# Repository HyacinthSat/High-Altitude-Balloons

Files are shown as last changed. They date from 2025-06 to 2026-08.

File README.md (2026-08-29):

# High-Altitude-Balloons  

~~高空气球，穷人的太空计划~~  
本仓库托管了风信子卫星项目下的一个高空气球项目  

该项目的主要目标为高空图像采集与回传，并围绕此目标开发了一系列的软件与硬件解决方案  
借助实现主要目的基本硬件，额外实现了业余无线电数字中继等功能  

主要作者：[BG7ZDQ](https://github.com/X-MQSI)  
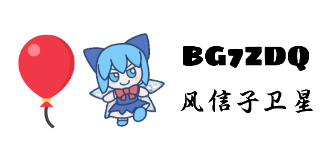
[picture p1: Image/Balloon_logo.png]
气球标识
  

飞行数据仪表板: [hab.satellites.ac.cn](https://hab.satellites.ac.cn/)  

## 项目功能  

- **实时遥测与追踪**：通过地面站实时接收、解析并展示气球的 GPS 位置、高度、速度、航向等关键遥测数据  
- **图像拍摄与回传**：支持将机载摄像头拍摄的图像通过 SSDV 协议进行编码和下传，并在地面站实时解码显示  
- **业余无线电通信**：集成数字中继功能，允许业余无线电爱好者通过气球作为数字中继进行远距离的通信实验  
- **Web 数据仪表板**：提供集成仪表板，整合了 SondeHub 实时追踪、飞行轨迹预测和遥测数据可视化图表  

## 系统展示  

- **气球载荷**  
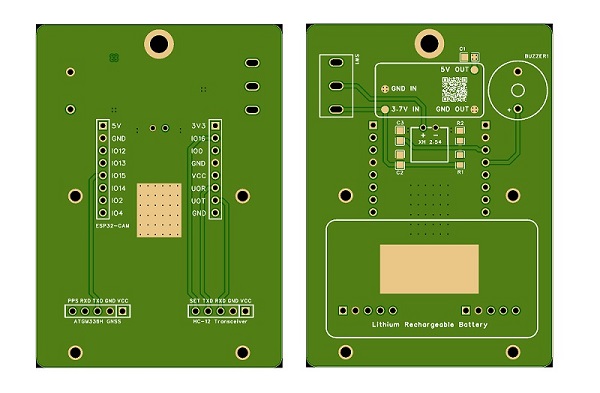
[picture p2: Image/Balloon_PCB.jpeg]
Balloon_PCB_仿真
  

- **可配置数传单元**  
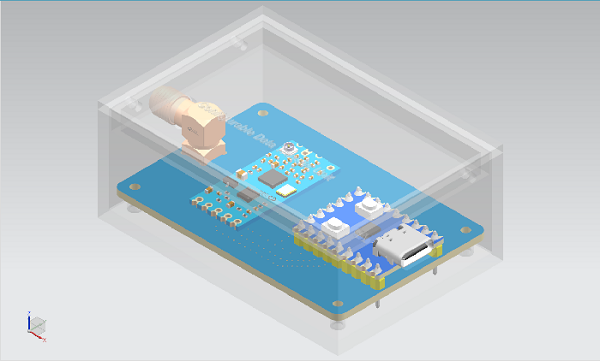
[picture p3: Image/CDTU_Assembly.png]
CDTU_装配


- **地面站程序**  
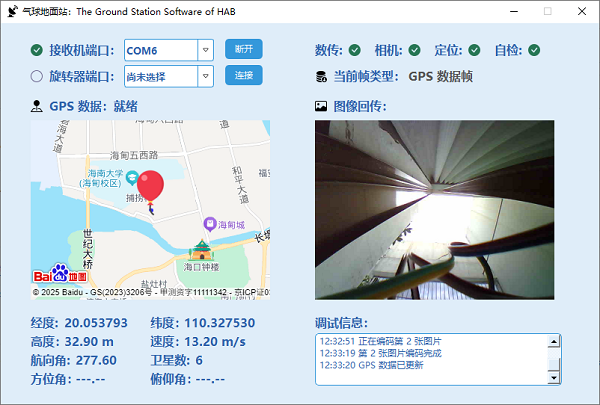
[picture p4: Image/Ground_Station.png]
Ground_Station


## 系统架构  
整个项目由三个主要部分组成：  

1. **[Balloon | 气球载荷](./Balloon)**  
气球飞行的核心控制器，负责所有机载任务。

- `/Balloon.h`: 定义了外设（如摄像头、传感器）的硬件引脚  
- `/Balloon.ino`: 主控程序。负责初始化板载硬件、采集传感器数据、构建遥测帧、捕获图像并使用 SSDV 协议编码，同时处理数字中继功能  
- `/ssdv.c` & `/ssdv.h`: SSDV 图像编码库。实现了将 JPEG 图像转换为一系列可无线传输的数据包的逻辑，来自 [fsphil ssdv](https://github.com/fsphil/ssdv/)  
- `/rs8.c` & `/rs8.h`: Reed-Solomon 前向错误校验库，为 SSDV 数据包提供容错能力，来自 [fsphil ssdv](https://github.com/fsphil/ssdv/)  
- `/Balloon_PCB_Ver_1.0.3.zip`: 气球端的电路设计，PCB制版文件、预览图片及其3D模型。使用立创 EDA 绘制  

2. **[CDTU | 可配置数传单元](./CDTU)**  
基于 RP2040-Zero 的智能数传模块控制器。  

- `/main.py`: 运行在 RP2040-Zero 上的核心程序。它将普通的 HC-12 数传模块升级为一个智能可配置的数传单元，实现了：  
  - 简易功能配置：免去了对硬件进行直接操作，智能识别解析配置指令，动态调整模块的参数  
  - 自适应波特率：存储了模块的配置参数，解决了串口通信的波特率管理问题    
  - 自动模式切换：通过硬件引脚控制模块在数据模式和命令模式间无缝切换  
  - 透明数据桥接：在默认模式下作为完全透明的数据传输桥  

- `CDTU_PCB_Ver_1.0.1.zip`: CDTU 的电路设计，PCB制版文件、预览图片及其3D模型。使用立创 EDA 绘制  

3. **[Ground Station | 地面站](./Ground%20Station)**  
功能强大的图形化地面站软件，是数据接收、状态监控和任务执行的控制中心。  

- `/GUI.py`: 基于 PyQt6 的地面站图形化主程序。 它负责：  
  - 连接、管理和控制测控用收发信机 CDTU  
  - 连接、管理和控制追踪气球的旋转器  
  - 气球的控制与状态监测  
  - 解析遥测、SSDV 图像数据和中继通信数据  
  - 上传数据至 SondeHub 进行多站点协作  
  - 基于遥测数据绘制实时轨迹  
  - 提供数字中继的客户端  

- `/sondehub.*`: 命令行工具，用于将遥测数据上传至 SondeHub  

- `/ssdv.exe`: 用于解码气球回传的 SSDV 协议图像的预编译程序，编译自 [fsphil ssdv](https://github.com/fsphil/ssdv/)。  

- `/web/`: 地面站 GUI 内嵌的地图和仪表板网页文件  
        * `map.html` & `map.js`: 内嵌于GUI的百度地图页面，用于显示气球和地面站的实时位置与轨迹  
        * `coordtransform.js`: 用于在不同地理坐标系之间转换的库，确保地图定位准确  
        * `index.html`: 项目主数据面板，简单整合了 SondeHub 实时追踪、飞行预测和 Grafana 遥测仪表盘  

## 使用说明  

1. **Ground Station | 地面站**  
- 运行环境:  
  - Python 3.11.0 及 相关依赖库：  
  (`pip install PyQt6 PyQt6-WebEngine pyserial numpy`)  

## 注意事项  

地面站程序使用了百度地图api，您可以直接使用 [https://hab.satellites.ac.cn/map](https://hab.satellites.ac.cn/map) ，或者将 `Ground Station/web` 目录下的内容托管到自己的服务器。  

## 开源许可  

本仓库在 MIT 许可证下发布。  
这意味着：  

- 任何人均可自由使用、复制、修改本仓库中的内容，包括个人和商业用途。  
- 允许以原始或修改后的形式分发本仓库的内容，但须附带原许可证声明，确保后续用户了解其授权条款。  
- 本仓库内容按“现状（as-is）”提供，不附带任何明示或暗示的担保，使用者需自行承担风险。  
- 仓库贡献者无需对使用本内容造成的任何损失或问题负责。  
- 其余未说明但未尽的事项。 更多信息请参见：[LICENSE](./LICENSE)  

**注意**：该许可证条款仅应用于本项目组所著之内容（除特有说明外），在其之外的代码、图片等任何内容均遵循源许可证或版权要求。

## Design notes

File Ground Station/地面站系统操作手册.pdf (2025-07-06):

# 临近空间智能观测与通信平台

# 地面站系统

操
作
手
册

## 二〇二五年七月

- 1 -

目录

1. 引言 | - 2 -
1.1 | 文档说明 | - 2 -
1.2 | 项目著作权 | - 2 -
2. 系统功能概述 | - 3 -
2.1 | 可配置数传单元 | - 3 -
2.2 | 地面站软件 | - 3 -
3. 运行环境 | - 4 -
3.1 | 硬件需求 | - 4 -
3.2 | 操作系统 | - 4 -
4. 操作说明 | - 5 -
4.1 | 收发信机安装 | - 5 -
4.2 | 软件安装 | - 6 -
4.3 | 软件首次运行 | - 8 -
4.4 | 软件使用 | - 9 -
4.4.1 | 基本操作 | - 9 -
4.4.2 | 更改地面站设置 | - 11 -
4.4.3 | 利用气球平台进行通信 | - 12 -
4.4.4 | 发送控制命令 | - 17 -
5. 云端平台 | - 19 -

- 2 -
1. 引言

1.1 文档说明

本文档是针对临近空间智能观测与通信平台下属的地面站系统

（以下简称为地面站系统）为用户所编写的操作手册。通过本文

档，用户可以全面的了解地面站系统的所有功能及基本操作方法。

1.2 项目著作权

项目著作权人：马志伟

- 3 -

## 2. 系统功能概述

2.1 可配置数传单元

本模块对来自气球端的无线数据进行接收。在提供基本透明数据

桥接之外，提供了运行时指令控制、波特率自动探测等功能。

除此之外，本模块利用 USB 虚拟串口的特性实现了与上位机通

信的波特率自适应，成为即插即用的便利设备。

在后文中，本模块将简称为收发信机。

2.2 地面站软件

本模块是功能强大的图形化程序，是高空气球系统数据接收、状

态监控和任务执行的控制中心，负责连接并配置管理可配置数传单

元，解析来自气球载荷的遥测数据、SSDV 图像数据以及数字中继通

信数据。

本模块内置地图模块，可实时绘制气球飞行轨迹；能够实时解码

并显示回传的 SSDV 图像；并提供数字中继通信实验平台客户端。

此外，地面站软件还支持向气球载荷发送远程控制指令，实现参数

配置和状态查询，确保对高空任务的全面掌控。同时，它还能将遥

测数据上传至 SondeHub 平台，并整合飞行预测和遥测仪表板，提

供丰富的数据可视化能力。

在后文中，本模块将简称为软件。

- 4 -

## 3. 运行环境

3.1 硬件需求

基于 X86-64 架构、处理器核心频率不低于 1.5 GHz 的计算机。

为确保稳定，计算机 USB 端口应提供不低于 5V 1A 的供电能力。

3.2 操作系统

基于 X86-64 架构的 Windows 8 以上的 Windows 操作系统。

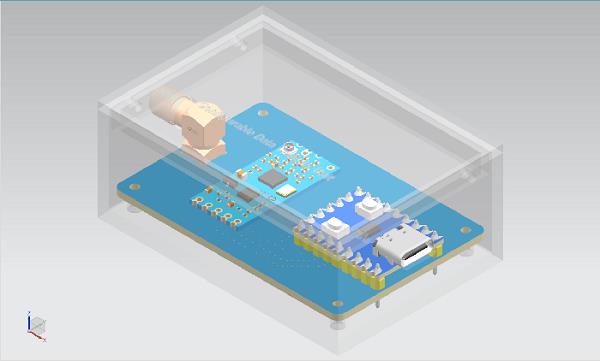
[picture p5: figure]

- 5 -

## 4. 操作说明

4.1 收发信机安装

收发信机具有一个 SMA 射频接口以及一个 Type-C 型 USB 数据

端口。其外观如下图所示：

用户应使用馈线将接收天线与收发信机进行连接，然后使用

Type-C 型 USB 数据线将收发信机连接至电脑。

连接至电脑后，应参照 4.4.4 节所提及的方式，发送 AT+RX 指令

进行收发信机检查。

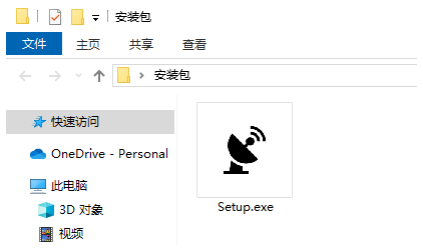
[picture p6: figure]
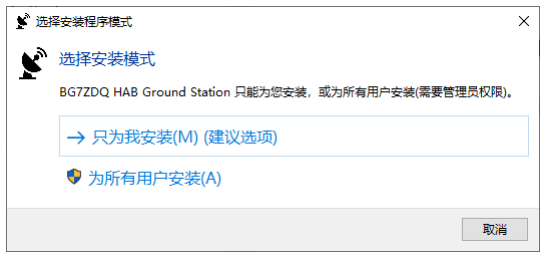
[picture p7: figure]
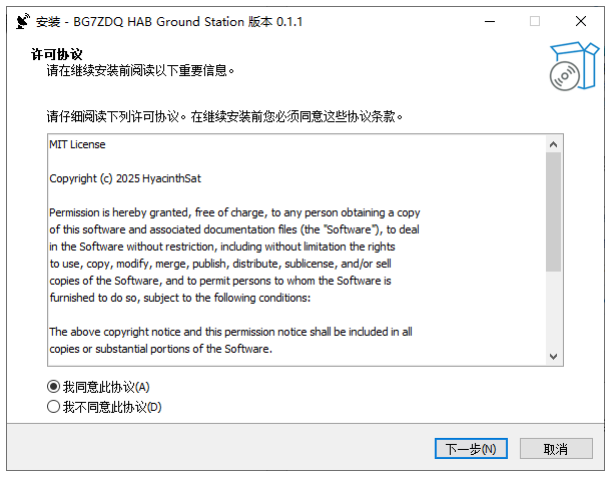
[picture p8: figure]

- 6 -

4.2 软件安装

首先，双击运行安装程序包“Setup.exe”:

选择程序的安装模式，推荐选择“只为我安装”。

用户阅读安装许可协议，决定是否同意。

随后，用户需要选择安装路径，并决定是否在桌面创建图标。

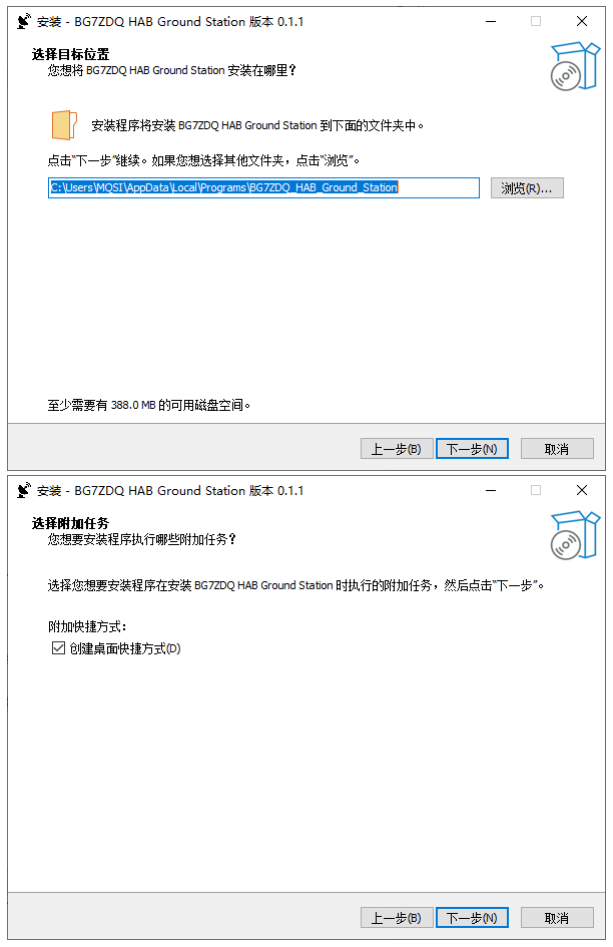
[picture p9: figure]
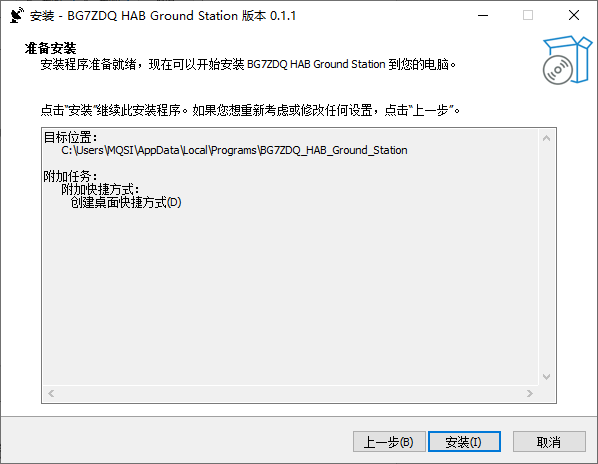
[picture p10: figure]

- 7 -

设置就绪后，确认选项，点击安装：

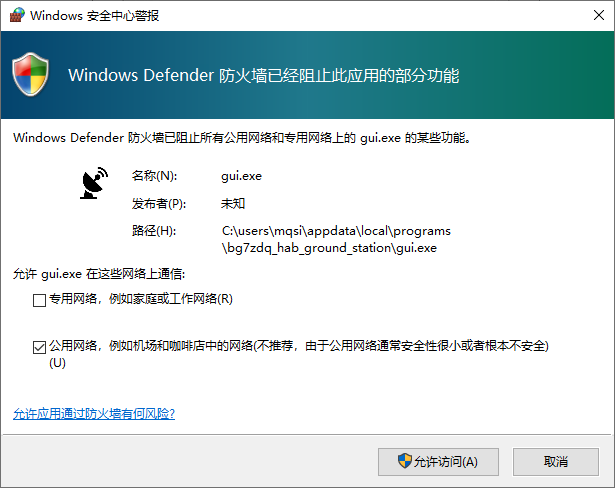
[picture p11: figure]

- 8 -

4.3 软件首次运行

安装结束后，在首次运行时系统会弹出防火墙设置。一般而言，

勾选默认的“公用网络”，点击允许访问即可。

软件需要地面站标识符（呼号）及地理信息以供跟踪、通信等功

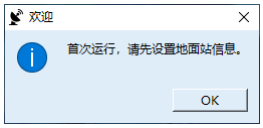
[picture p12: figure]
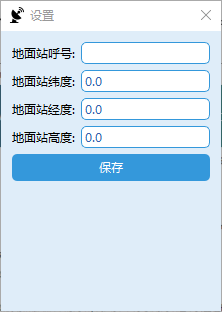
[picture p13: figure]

能使用。首次运行时将会弹出输出窗口。依据实际信息填写后，点

击保存按钮即可。

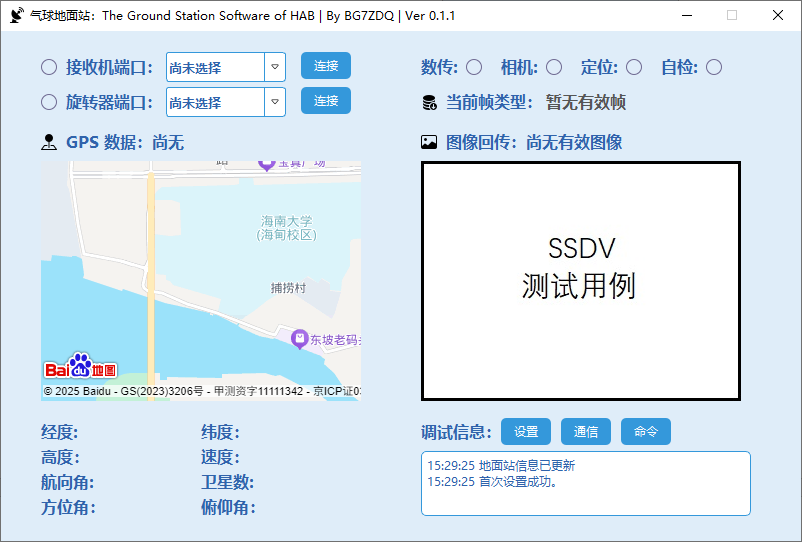
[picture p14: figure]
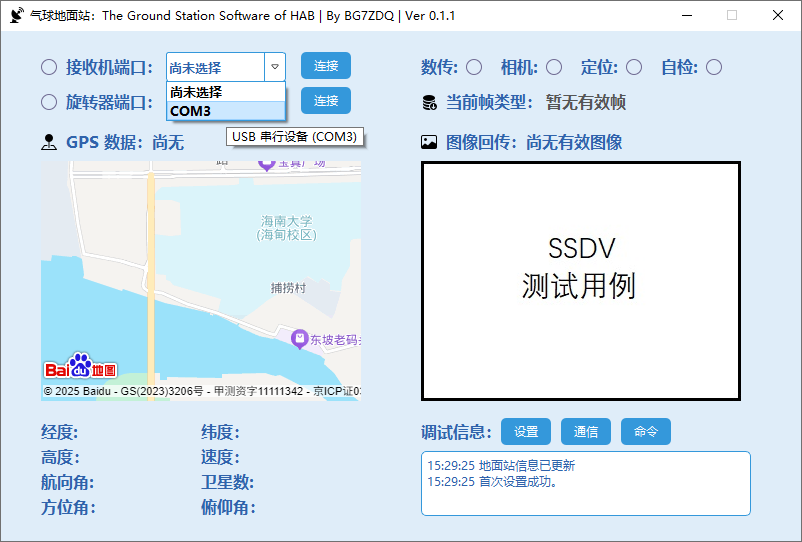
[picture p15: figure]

- 9 -

4.4 软件使用

4.4.1 基本操作

在完成首次运行的设置后，软件启动时将展现主界面：

用户需将接收机连接至电脑。连接成功后，点击接收机端口下拉

列表，可以查看已连接设备。在列表中找到接收机所在端口，单击

选中，并单击“连接”按钮即可完成连接。

- 10 -

连接成功之后，应参照 4.4.4 节所提及的方式，发送 AT+RX 指令

进行收发信机检查。若无问题，用户即可依据软件计算出的方位角

与俯仰角信息，操纵天线开始持续跟踪气球平台。

气球平台在发送数据后，收发信机将接收并进行解码，随后原始

数据会经由串口传入软件，由软件自动完成解析并上传云端平台。

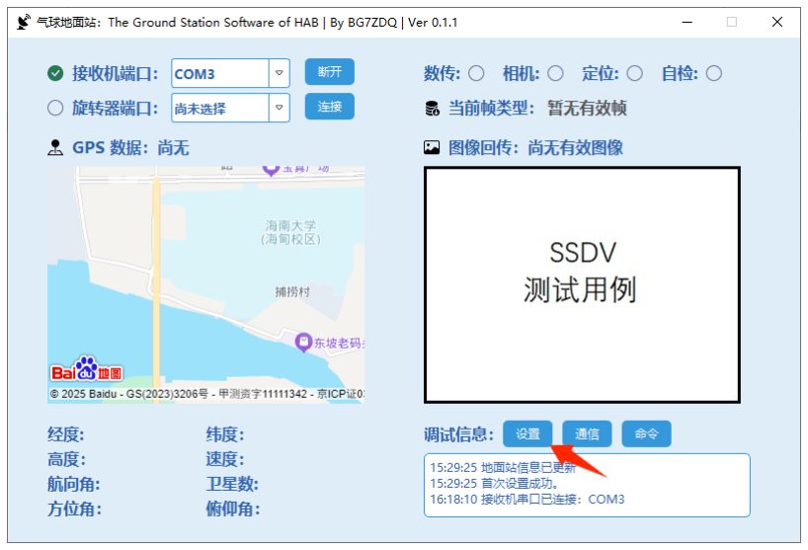
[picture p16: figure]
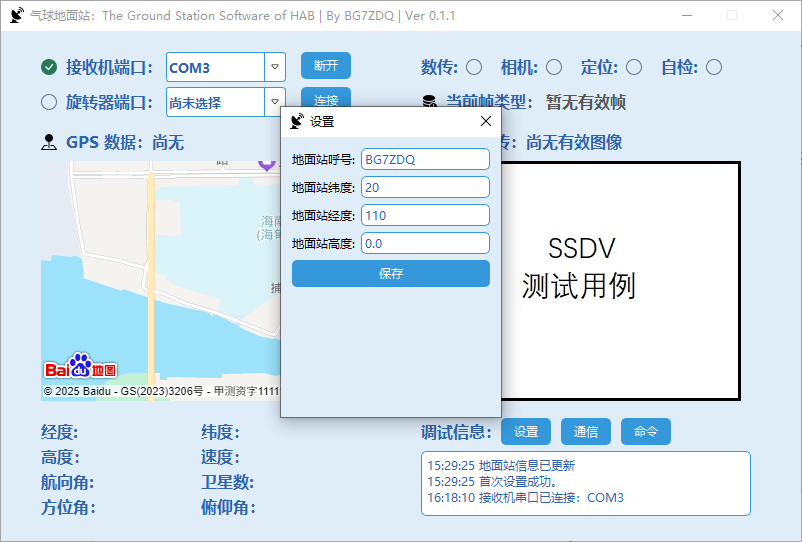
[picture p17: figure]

- 11 -

4.4.2 更改地面站设置

用户若在后续的操作中需要对地面站位置进行更改，可以点击

“调试信息”旁的“设置”按钮。

随后将弹出设置窗口，按照 4.3 节所述，填写实际信息即可。

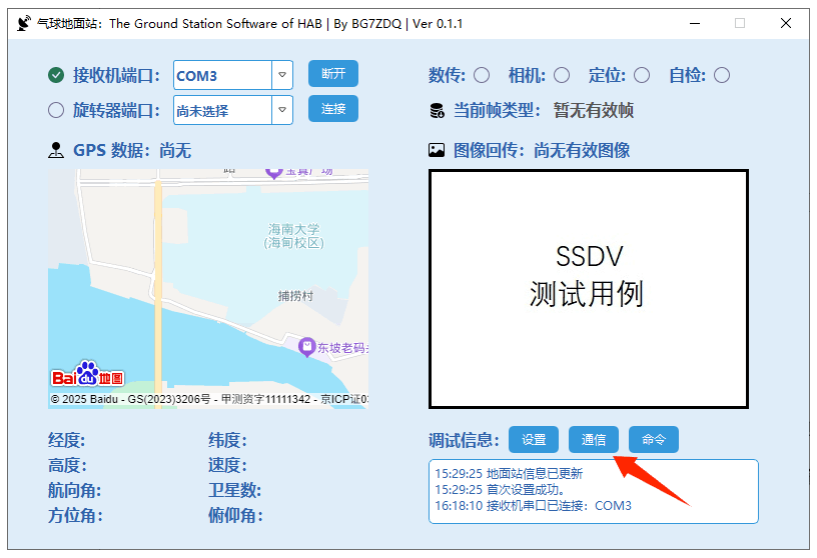
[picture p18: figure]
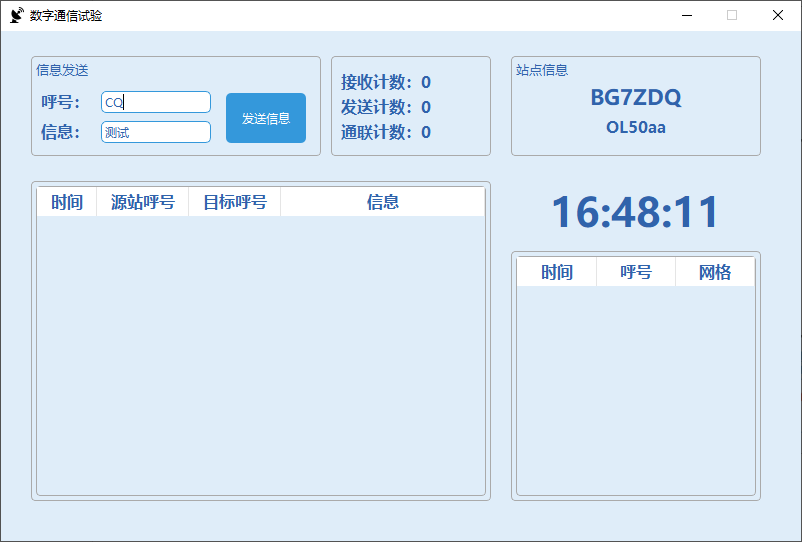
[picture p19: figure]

- 12 -

4.4.3 利用气球平台进行通信

气球平台带有信息转发功能，可用于台站之间的相互通信实验。

软件提供了单独的客户端，并且以业余无线电基本通联规则设置了

简单的记录与智能回复功能。

如需使用客户端，用户需点击“调试信息”旁的“通信”按钮：

通信客户端基本布局如下，共分为六部分：

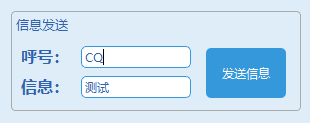
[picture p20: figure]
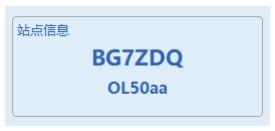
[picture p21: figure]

- 13 -

信息发送区: 位于客户端左上方，包含“呼号”输入框和“信

息”输入框，以及用于发送消息的“发送信息”按钮。用户在此处

填写接收方呼号和需要发送的文本信息。

图：信息发送区

信息统计区: 位于客户端中上方，实时显示通信的统计数据，包

括接收消息数量、发送消息数量和已建立通联的数量。

图：信息统计区

站点信息区: 位于客户端右上方，展示当前地面站的呼号和地理

网格信息，用于标识本台站身份。

图：站点信息区

通联信息表格: 位于客户端左下方，以表格形式记录了所有接收

和发送的通信信息，包含了接收/发送时间、源站呼号、目标呼号和

具体信息内容等信息。

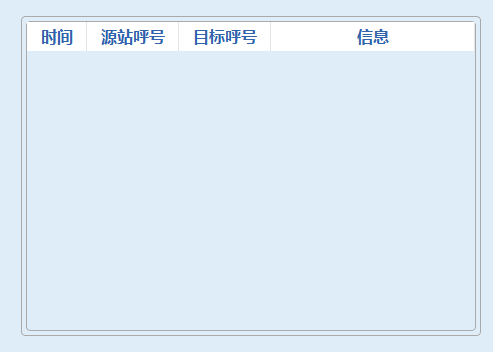
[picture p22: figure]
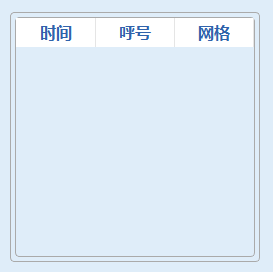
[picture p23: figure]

- 14 -

图：信息发送区

实时时钟显示: 位于客户端右侧中间，显示当前实时时间。

图：实时时钟显示

通联记录表格: 位于客户端右下方，记录与不同台站成功建立通

联（QSO）的信息，包括通联时间、对方呼号和网格信息。

图：通联记录表格

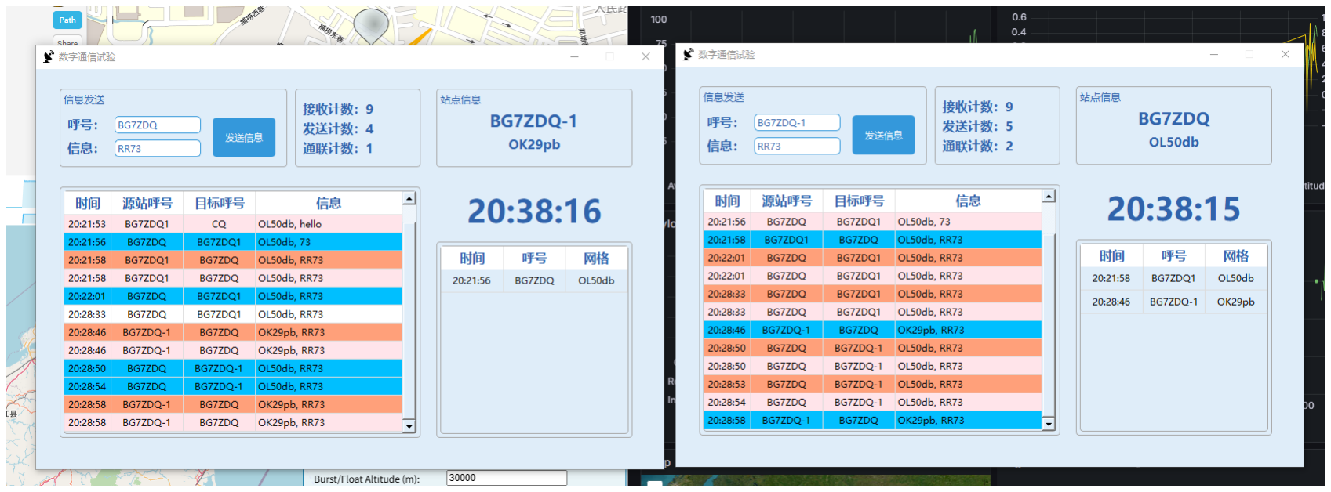
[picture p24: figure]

- 15 -

发送信息或收到信息时，系统将自动添加消息至通联信息表格。

根据消息的来源和目标，表格中的条目会以不同颜色显示，便于用

户快速识别：

⚫ | 发送自本台站的消息将显示为橙色。
⚫ | 转发回来的本台站的消息将显示为粉色。
⚫ | 呼叫目标为本台站的消息将显示为蓝色。
⚫ | 其他台站发出的“CQ”（广泛呼叫）消息将显示为紫色。
⚫ | 其他普通消息则显示为白色。

同时，接收计数会相应增加。另外的，如果接收到的消息是发给

本台站的，且内容中包含“73”，系统则认为完成一次通联，并将

在 QSO 表格中自动添加一条通联记录。

通联信息表格支持自动滚动到底部，如果用户手动向上滚动，则

会出现“滚动到底部”按钮，方便用户随时跳转到最新消息。

- 16 -

用户还可以双击表格进行快速回复，系统将根据消息内容智能填

充回复对象与信息，方便用户进行常规通联：

⚫ | 当收到“CQ”消息时，双击可回复“73, QSL?”进行呼叫，
| 尝试与对方进行通联。
⚫ | 当收到“73, QSL?”消息时，双击可回复“RR73, TNX!”表示
| 确认与对方完成通联。

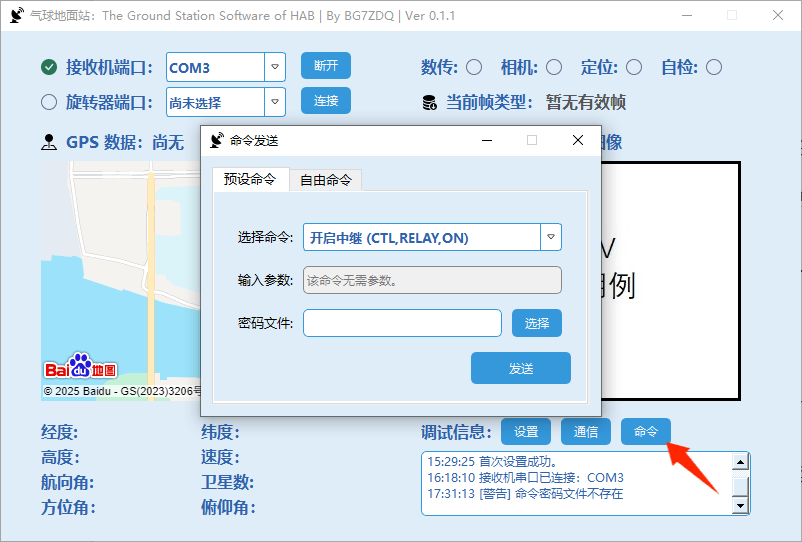
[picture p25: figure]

- 17 -

4.4.4 发送控制命令

气球平台在飞行过程中可能需要受地面站控制进行某些设置上的

变更。地面站软件提供了专用的命令发送客户端来实现此功能。

用户可通过主界面“调试信息”旁的“命令”按钮进入客户端。

该客户端分为“预设命令”和“自由命令”两个选项卡：

- 预设命令：提供了一系列指令的快捷下拉菜单，用户选择后可

根据需要输入相应参数。

- 自由命令：提供一个文本输入框，允许用户手动输入符合协议

格式的自定义命令进行发送。

所有发送的控制命令均通过收发信机传输至气球平台。为了保障

飞行安全，客户端发送命令时需要附带一份密码文件进行验证，以

防止未经授权的控制。

- 18 -

除去对气球平台的控制外，该客户端同样可以对可配置输传单元

进行配置与查询。

对可配置传输单元进行配置与查询，则需要切换至“自由命令”

选项卡，以下为可用命令：

⚫ | 重配波特率：AT+B<baud>
⚫ | 重配信道号：AT+C<chan>
⚫ | 状态查询：AT+RX

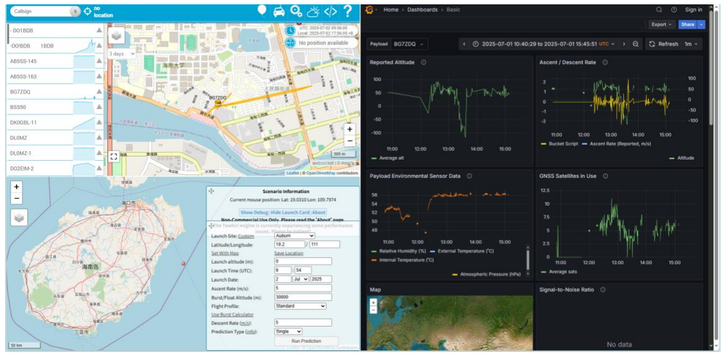
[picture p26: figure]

- 19 -

## 5. 云端平台

软件部分将数据传至 Sondehub 服务器，并由 Sondehub 提供气球

平台的轨迹记录以及所有遥测数据的数据面板。

用户可访问 https://hab.satellites.ac.cn 查看该面板。

- 20

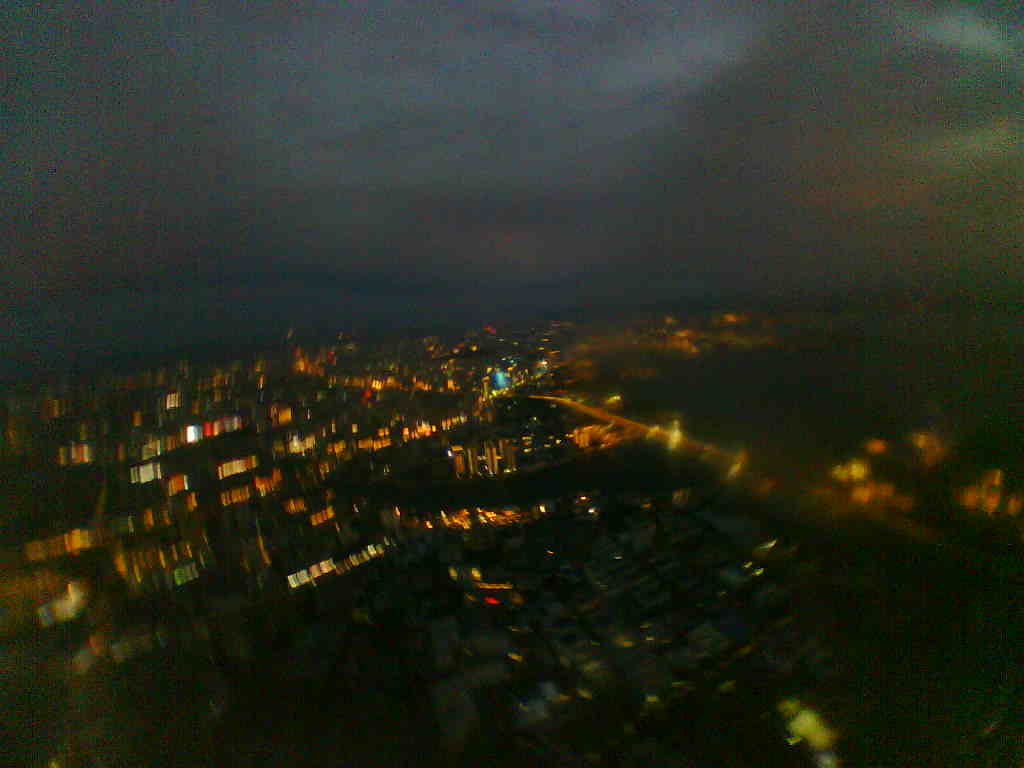
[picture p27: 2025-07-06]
2025.07.06/original_image/d2025-07-06_19-34-27.jpg

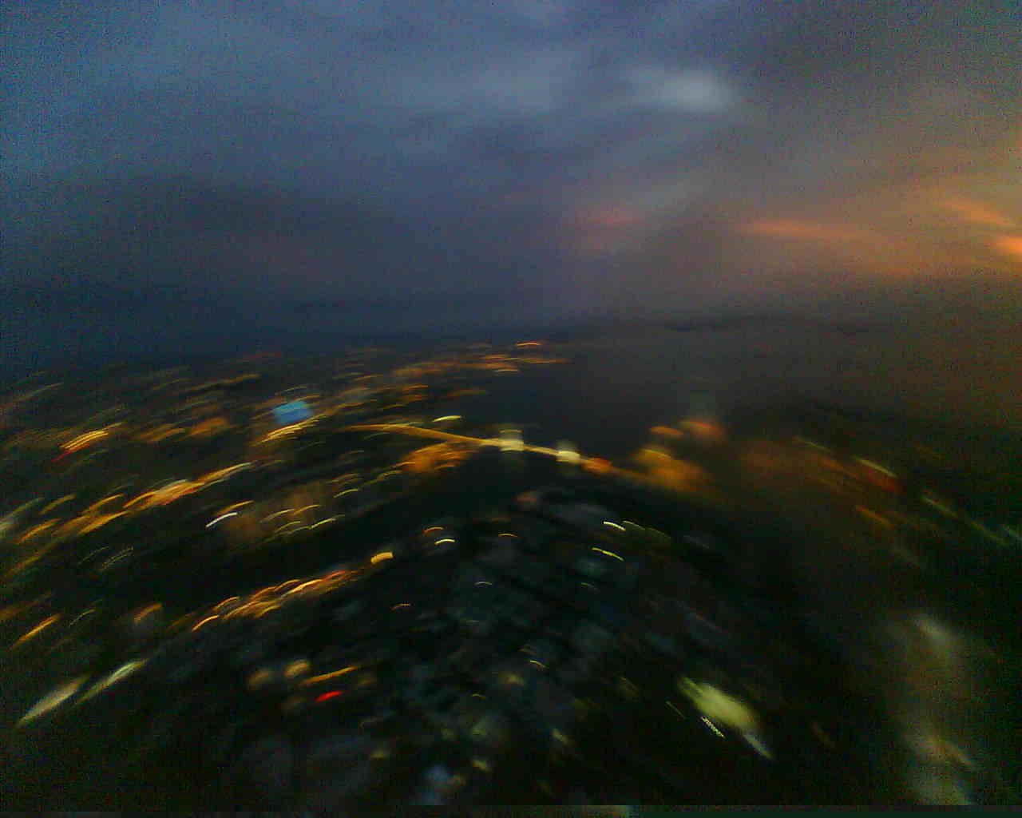
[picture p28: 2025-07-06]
2025.07.06/original_image/d2025-07-06_19-33-21.jpg

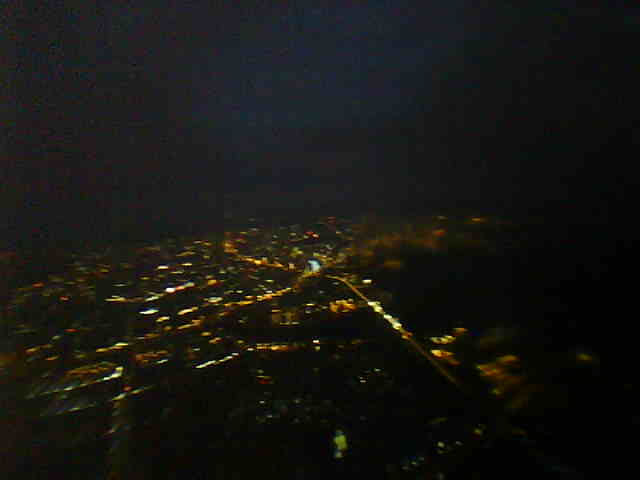
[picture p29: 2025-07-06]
2025.07.06/original_image/d2025-07-06_19-40-09.jpg

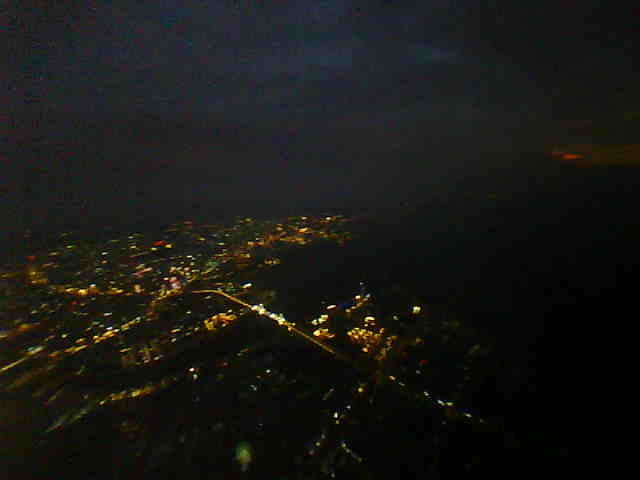
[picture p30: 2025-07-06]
2025.07.06/original_image/d2025-07-06_19-39-45.jpg

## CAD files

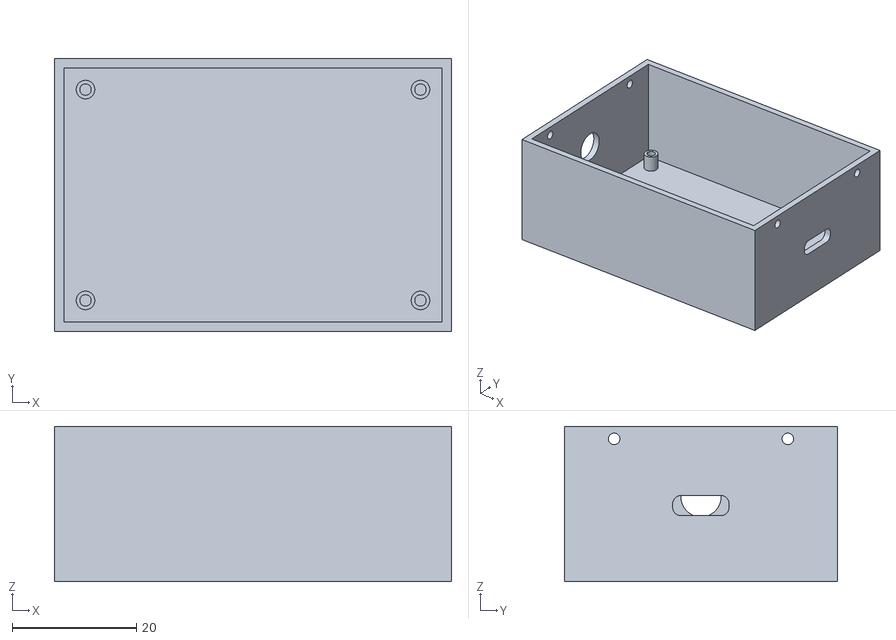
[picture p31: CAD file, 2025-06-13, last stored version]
CDUT/CDTU_盒子.stl
64.0 x 44.0 x 25.0

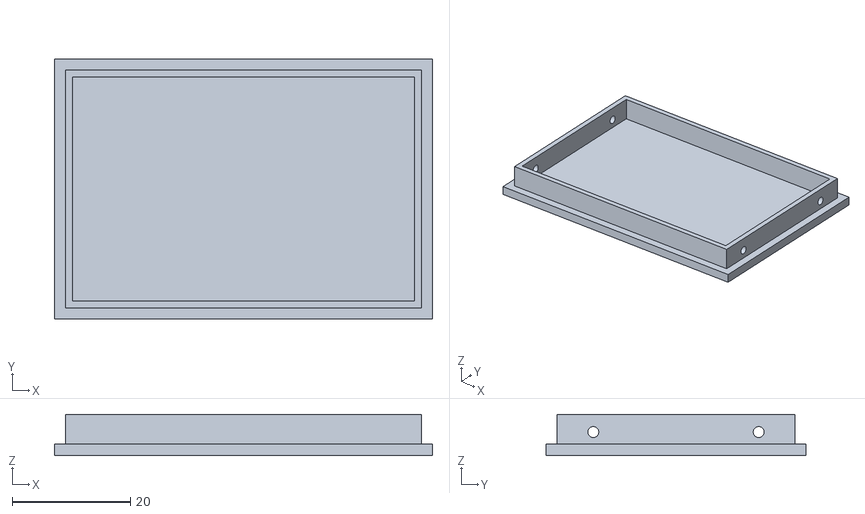
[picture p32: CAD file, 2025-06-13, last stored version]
CDUT/CDUT_盖子.stl
64.0 x 44.0 x 7.00

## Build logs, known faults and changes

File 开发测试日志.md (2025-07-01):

# 项目开发与测试日志

---

## 📅 2025/06/21

### ✅ 测试日志

#### 气球固件部分

1. [有待调整]  `payload` 参数结构不便于阅读  
2. [严重故障]  NACK 命令存在失效的情况  
3. [严重故障]  图像传输期间命令完全不响应  
4. [严重故障]  温度在最开始遥测帧中正常，后续固定为 53.33℃  
5. [非预期行为] 第一张图编号为 0，被误判为 ERR_NONE，未进行传输  
6. [非预期行为] 修改画幅与周期后图像连发，疑似调制完成过快导致休眠时链路仍未发送完  

✅ **已修复：** 1, 2, 3, 4, 5, 6

---

## 📅 2025/06/22

### ✅ 开发日志

#### 错误修复记录

1. [完成] 重构了 `payload` 参数         
2. [完成] 修复了应答流程  
3. [完成] 修复图像传输期间命令不响应逻辑  
4. [鸽了] 问题暂未查明，交付后期处理  
5. [完成] 与 `payload` 重构一并解决  
6. [成功] 新增队列检查机制，确保发送完成后才进入周期延时  

---

### ✅ 测试日志

#### 气球固件部分

1. [非预期行为] 转发器文本格式存在问题  
2. [非预期行为] GPS 指示器显示为 “~”  
3. [非预期行为] 降级状态下图像帧并非最新  
4. [非预期行为] SSDV 调制结束但未发送完，结束标记插队  
5. [非预期行为] 图传期间命令响应延迟到图传结束后才发送  
6. [非预期行为] 内部温度传感器误差大，室温 30℃ 时显示近 50℃  
7. [非预期行为] 中继关闭期间不收但也不丢弃消息，恢复后读出积压数据  
8. [严重故障]   遥测温度固定为 53.33℃，注释掉电压 ADC 后恢复  

✅ **已修复：** 1, 2, 3, 4, 5, 7, 8  
🚫 **不予处理：** 6（误差属设计固有限制）

---

#### CDTU 固件部分

- [严重故障] 长时间待机后串口设备没有发挥作用

✅ **已修复** 

---

#### 地面站部分

1. [非预期行为] 串口连接失败时未弹窗提示  
2. [非预期行为] 曾尝试连接过的串口断开时仍会弹出提示  

---

#### 其他硬件

- [修复查明] GPS 故障已确认为由天线引起

---

### 📌 TODO

- 降级状态下图像帧的实时性检查  
- 开发命令上注加密与鉴权机制

---

## 📅 2025/06/23

### ✅ 开发日志

#### 错误修复记录

1. [完成] 修复转发器逻辑，删除错误的 `CALLSIGN` 字段  
2. [完成] 修复字面量类型错误，重构 DEBUG_MODE 逻辑  
3. [完成] 删除帧降级机制，经测试确认无风险  
4. [完成] 调整错误的状态通知位置，修复结束标记时机  
5. [完成] 增加高优先级数据插队机制  
6. [放弃] 温度误差为正常范围，暂不处理  
7. [完成] 优化中继数据接收逻辑  
8. [完成] 使用寄存器重置方式解决温度传感器无效问题  

---

## 📅 2025/06/25

### ✅ 测试日志

#### 气球固件部分

- [严重错误] 图像传输接近末尾时发生丢帧或帧错误

---

## 📅 2025/06/26 - 2025/06/27

### ✅ 测试日志

#### 气球固件部分

1. [有待调整] 图传参数错误时未发送 NACK
2. [严重错误] SVGA 尺寸下存在编码问题，疑似其宽度不受支持

#### 地面站部分

1. [非预期行为] 中继窗口的返回键未显示
2. [非预期行为] 依赖文件检测机制使用相对路径，存在路径误判问题
3. [非预期行为] 信息发送失败时计数器仍然增加

### ✅ 开发日志

#### 错误修复记录

- [完成] 经测试，确认图传问题由降低 CPU 频率引起波特率紊乱，予以500ms延时
- [完成] 修复中继窗口返回键显示问题
- [完成] 修复依赖文件检测机制，使用绝对路径
- [完成] 修复信息发送失败计数器增加问题
- [完成] 修复图像传输参数错误时未发送 NACK 问题
- [完成] 修复 SVGA 下编码问题，更换为 XGA

#### 功能更新

- [完成] 增加预设图片选项，现在可以通过@@SET,SSDV_PRESET命令设置预设图片

---

## 📅 2025/06/30

### ✅ 开发日志

#### 功能更新

- [完成] 新增上行链路密码验证机制，防止未授权控制

### ✅ 测试日志

#### 气球固件部分

1. [严重错误] 发送查询命令时发生崩溃
2. [非预期行为] 命令NACK等反馈不及时，疑似图像发送结束后才进行处理

## 📅 2025/07/01

### ✅ 测试日志

#### 气球固件部分

1. [严重错误] 图像编码发生死锁触发看门狗

#### 地面站部分

1. [非预期行为] 通联窗口时钟位置偏移
2. [非预期行为] 双击选中时不会清空原有的信息
3. [非预期行为] 封装后，Debug 信息会弹出窗口

### ✅ 开发日志

#### 错误修复记录

- [完成] 查询命令由于字段缺乏而崩溃，问题已解决
- [完成] NACK同样由字段问题引起，问题已解决
- [尝试] 经过排查疑似投喂部分可能存在死锁风险，添加计数与超时计数尝试解决

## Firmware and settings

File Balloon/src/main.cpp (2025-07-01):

/*
 * Firmware for an ESP32-based High-Altitude Balloon (HAB) Tracker.
 *
 * This program is firmware designed for an ESP32-based high-altitude balloon (HAB) payload.
 * It utilizes the FreeRTOS operating system to perform multiple tasks concurrently,
 * including capturing images with a camera and encoding them into SSDV packets,
 * as well as collecting telemetry data such as GPS position, altitude, speed, internal temperature, and battery voltage.
 * All data (telemetry and SSDV) is transmitted via a serial port for radio downlink.
 * This firmware provides a complete flight control and data acquisition solution for HAB missions.
 *
 * Author: BG7ZDQ
 * Date: 2025/06/27
 * Version: 1.0.1
 * LICENSE: GNU General Public License v3.0
 */

// 系统开发状态
#define DEBUG_MODE false

/* --- 综合头文件 --- */

// 核心配置文件和类型定义
#include "config.h"
#include "status_codes.h"

/* --- 系统配置与状态变量 --- */

// 定义并初始化系统动态配置变量
SystemConfig_t g_systemConfig = {
  .cameraImageSize     = FRAMESIZE_VGA,    // 默认摄像机图像尺寸: VGA
  .cameraImageQuality  = 5,                // 默认摄像机图像质量: 5
  .ssdvPacketType      = SSDV_TYPE_NOFEC,  // 默认 SSDV 数据类型: NOFEC
  .ssdvEncodingQuality = 2,                // 默认 SSDV 编码质量: 2
  .ssdvCycleTimeSec    = 60,               // 默认 SSDV 发送周期: 60
  .ssdvPresetMode      = 0,                // 默认 SSDV 预设照片: 0 (无预设)
};

// 定义并初始化系统实时状态变量
SystemStatus_t g_systemStatus = {
  .isRelayEnabled            = true,       // 中继功能默认开启
  .isSsdvEnabled             = true,       // 图传功能默认开启
  .isBuzzerEnabled           = true,       // 蜂鸣功能默认开启
  .isSsdvTransmitting        = false,      // 图传状态默认为否
};

// 定义初始化状态
bool Initialization_Status = true;

// 声明互斥锁
SemaphoreHandle_t g_configMutex = xSemaphoreCreateMutex();  // 配置参数结构体互斥锁
SemaphoreHandle_t g_stateMutex  = xSemaphoreCreateMutex();  // 状态参数结构体互斥锁
SemaphoreHandle_t cameraMutex   = xSemaphoreCreateMutex();  // 摄像头硬件资源互斥锁

// 声明各类队列
QueueHandle_t txQueue;     // 数据发送队列
QueueHandle_t cmdQueue;    // 命令接收队列
QueueHandle_t relayQueue;  // 中继信息队列

// FreeRTOS 任务句柄
TaskHandle_t DatalinkTaskHandle  = NULL;
TaskHandle_t CommandTaskHandle   = NULL;
TaskHandle_t TelemetryTaskHandle = NULL;
TaskHandle_t SSDVTaskHandle      = NULL;
TaskHandle_t RelayTaskHandle     = NULL;

/* --- 遥测模块相关变量 --- */
char TelemetryMessage[256];      // 初始化遥测数据缓冲区
uint16_t Telemetry_Counter = 0;  // 初始化遥测帧计数器

/* --- GPS 模块相关对象 --- */
HardwareSerial GPS_Serial(2);    // GPS 硬件串口分配 (RX on GPIO15, TX on default -1)
char GPS_Timestamp[21];          // GPS 时间戳缓冲区
TinyGPSPlus gps;                 // GPS 解析库对象

/* --- ADC 及传感器相关变量 --- */
esp_adc_cal_characteristics_t adc_chars;    // ADC 校准参数
extern "C" uint8_t temprature_sens_read();  // ROM 内部的温度传感器函数

/* --- SSDV 模块相关变量 --- */
ssdv_t ssdv;              // SSDV 编码器结构体
uint8_t ssdvImageId = 0;  // SSDV 编码器图像计数

/* --- 函数部分 --- */

// 线程安全地获取当前系统动态配置变量的完整副本
void GET_System_Config(SystemConfig_t* config_copy) {
  if (xSemaphoreTake(g_configMutex, portMAX_DELAY) == pdTRUE) {
    memcpy(config_copy, &g_systemConfig, sizeof(SystemConfig_t));
    xSemaphoreGive(g_configMutex);
  }
}

// 使用提供的新配置，线程安全地更新整个系统配置
void Update_System_Config(const SystemConfig_t* new_config) {
  if (xSemaphoreTake(g_configMutex, portMAX_DELAY) == pdTRUE) {
    memcpy(&g_systemConfig, new_config, sizeof(SystemConfig_t));
    xSemaphoreGive(g_configMutex);
  }
}

// 线程安全地获取当前系统实时状态变量的完整副本
void GET_System_Status(SystemStatus_t* new_status) {
  if (xSemaphoreTake(g_stateMutex, portMAX_DELAY) == pdTRUE) {
    memcpy(new_status, &g_systemStatus, sizeof(SystemStatus_t));
    xSemaphoreGive(g_stateMutex);
  }
}

// 使用提供的新状态，线程安全地更新系统实时状态变量
void Update_System_Status(SystemStatusParam_t param, bool value) {
  // 在锁的保护下根据传入的枚举来精确地修改一个成员
  if (xSemaphoreTake(g_stateMutex, portMAX_DELAY) == pdTRUE) {
    switch (param) {
      case RELAY_ENABLED_STATUS:
        g_systemStatus.isRelayEnabled = value;
        break;
      case SSDV_ENABLED_STATUS:
        g_systemStatus.isSsdvEnabled = value;
        break;
      case BUZZER_ENABLED_STATUS:
        g_systemStatus.isBuzzerEnabled = value;
        break;
      case SSDV_TRANSMITTING_STATUS:
        g_systemStatus.isSsdvTransmitting = value;
        break;
      default:
        break;
    }
    xSemaphoreGive(g_stateMutex);
  }
}

// 数据发送请求接口
/* --- 函数部分 --- */

// 数据发送请求接口
bool Transmit_Data(const uint8_t *data, size_t length, bool is_binary, bool send_to_front = false) {

  // 检查发送缓冲区是否可容纳数据
  if (length > MAX_TX_BUFF_SIZE) return false;

  RadioPacket_t packet;
  packet.length = length;
  packet.is_binary = is_binary;
  memcpy(packet.data, data, length);

  // 将数据包发送到队列，如果队列满了，等待500ms，最多重试三次
  for (int i = 0; i < 3; i++) {

    // 尝试将数据包放入队列
    // 根据 send_to_front 参数的值，决定调用哪个 FreeRTOS API
    if (send_to_front) {
      // 如果为 true，则进行插队
      if (xQueueSendToFront(txQueue, &packet, pdMS_TO_TICKS(500)) == pdTRUE) {
        return true;
      }
    } else {
      // 如果为 false，则仍然排队
      if (xQueueSend(txQueue, &packet, pdMS_TO_TICKS(500)) == pdTRUE) {
        return true;
      }
    }

    // 短暂挂起任务，给数据链路任务留出时间来处理和清空队列
    vTaskDelay(pdMS_TO_TICKS(50));
  }

  // 如果重试后最终失败
  return false;
}

// 文本信息发送请求接口
bool Transmit_Text(const char *format, ...) {

  char buffer[MAX_TX_BUFF_SIZE];
  size_t offset = 0;

  // 写入固定的帧头
  offset = snprintf(buffer, MAX_TX_BUFF_SIZE, "** ");

  // 写入内容
  va_list args;
  va_start(args, format);
  vsnprintf(buffer + offset, MAX_TX_BUFF_SIZE - offset, format, args);
  va_end(args);

  // 追加帧尾
  offset = strlen(buffer);
  snprintf(buffer + offset, MAX_TX_BUFF_SIZE - offset, " **");

  // 获取最终帧的长度
  size_t total_length = strlen(buffer);

  // 调用底层发送函数
  for (int i = 0; i < 3; i++) {
    if (Transmit_Data((uint8_t *)buffer, total_length, false, true)) {
      return true;
    }
    vTaskDelay(pdMS_TO_TICKS(100));
  }

  return false;
}

// 状态码发送请求接口
void Transmit_Status(StatusCode_t code, const char* info) {
  if (info == nullptr || info[0] == '\0') {
    Transmit_Text("Code: 0x%04X", code);
  } else {
    Transmit_Text("Code: 0x%04X, Info: %s", code, info);
  }
}

// 重载1 发送不带任何附加信息的状态码
void Transmit_Status(StatusCode_t code) {
  Transmit_Status(code, nullptr);
}

// 重载2 发送带数字 Payload 的状态码
void Transmit_Status(StatusCode_t code, int payload) {
  char buffer[20];
  snprintf(buffer, sizeof(buffer), "%d", payload);
  Transmit_Status(code, buffer);
}

// 重载3 发送带布尔值 Payload 的状态码
void Transmit_Status(StatusCode_t code, bool payload) {
  Transmit_Status(code, payload ? "1" : "0");
}

// 告警提醒
void Signal_Error() {
  SystemStatus_t local_status;
  GET_System_Status(&local_status);
  if (local_status.isBuzzerEnabled) {
    for (int i = 0; i < 3; i++) {
      digitalWrite(BUZZER, HIGH);
      vTaskDelay(pdMS_TO_TICKS(50));
      digitalWrite(BUZZER, LOW);
      vTaskDelay(pdMS_TO_TICKS(50));
    }
  }
  Initialization_Status = false;
}

// 就绪提醒
void Signal_Ready() {
  digitalWrite(BUZZER, HIGH);
  vTaskDelay(pdMS_TO_TICKS(100));
  digitalWrite(BUZZER, LOW);
}

// 初始化就绪检查
void Initialization_Check() {

  // 检查初始化变量
  if (Initialization_Status) {
    Signal_Ready();
  } else {
    Transmit_Status(SYS_INIT_FAIL);
    digitalWrite(BUZZER, HIGH);
    vTaskDelay(pdMS_TO_TICKS(2000));
    digitalWrite(BUZZER, LOW);
    esp_restart();
  }
  
  // 开发者模式指示
  if (DEBUG_MODE){
    Transmit_Status(SYS_DEV_MODE_ENABLED);
  }
}

// 尝试挂载 SPIFFS 文件系统
void Setup_SPIFFS() {
  // 检查 SPIFFS 是否成功挂载
  if(!SPIFFS.begin(true)){
    Transmit_Status(SPIFFS_MOUNT_FAIL, "SPIFFS Mount Failed");
    Signal_Error();
  }
}

// 配置摄像头信息
bool Setup_Camera() {

  // 通知地面站摄像头开始初始化
  Transmit_Status(CAM_INIT_START);

  // 获取当前配置
  SystemConfig_t local_config;
  GET_System_Config(&local_config);

  camera_config_t config;
  config.ledc_channel  = LEDC_CHANNEL_0;
  config.ledc_timer    = LEDC_TIMER_0;
  config.pin_d0        = CAM_PIN_Y2_GPIO_NUM;
  config.pin_d1        = CAM_PIN_Y3_GPIO_NUM;
  config.pin_d2        = CAM_PIN_Y4_GPIO_NUM;
  config.pin_d3        = CAM_PIN_Y5_GPIO_NUM;
  config.pin_d4        = CAM_PIN_Y6_GPIO_NUM;
  config.pin_d5        = CAM_PIN_Y7_GPIO_NUM;
  config.pin_d6        = CAM_PIN_Y8_GPIO_NUM;
  config.pin_d7        = CAM_PIN_Y9_GPIO_NUM;
  config.pin_xclk      = CAM_PIN_XCLK_GPIO_NUM;
  config.pin_pclk      = CAM_PIN_PCLK_GPIO_NUM;
  config.pin_vsync     = CAM_PIN_VSYNC_GPIO_NUM;
  config.pin_href      = CAM_PIN_HREF_GPIO_NUM;
  config.pin_sccb_sda  = CAM_PIN_SIOD_GPIO_NUM;
  config.pin_sccb_scl  = CAM_PIN_SIOC_GPIO_NUM;
  config.pin_pwdn      = CAM_PIN_PWDN_GPIO_NUM;
  config.pin_reset     = CAM_PIN_RESET_GPIO_NUM;
  config.xclk_freq_hz  = 20000000;
  config.pixel_format  = PIXFORMAT_JPEG;
  config.frame_size    = local_config.cameraImageSize;
  config.jpeg_quality  = local_config.cameraImageQuality;
  config.fb_count      = 2;
  config.grab_mode     = CAMERA_GRAB_LATEST;

  // 应用配置并检查返回状态
  esp_err_t err = esp_camera_init(&config);
  if (err != ESP_OK) {
    // 发送失败状态码，并附带错误信息
    Transmit_Status(CAM_INIT_FAIL, err);
    return false;
  }
  
  // 通知地面站初始化成功
  Transmit_Status(CAM_INIT_OK);

  return true;
}

// 拍摄多次进行摄像头校准 (自动曝光/白平衡稳定)
bool Camera_Calibrate() {

  // 通知地面站
  Transmit_Status(CAM_CALIBRATE_START);

  // 拍摄多次进行校准
  for (int i = 0; i < CAM_CALIBRATE_TIMES; i++) {
    camera_fb_t *fb = esp_camera_fb_get();
    if (!fb) {
      Transmit_Status(CAM_CALIBRATE_FAIL);
      Signal_Error(); 
      return false;
    }
    vTaskDelay(pdMS_TO_TICKS(500));
    esp_camera_fb_return(fb);
  }

  // 通知地面站校准成功
  Transmit_Status(CAM_CALIBRATE_OK);
  return true;
}

// 安全地重新配置摄像头
bool Reconfigure_Camera() {

  // 先卸载当前摄像头驱动
  esp_camera_deinit();

  // 使用全局变量重新初始化
  if (!Setup_Camera()) return false;

  // 重新校准
  if (!Camera_Calibrate()) return false;

  // 一切正常则返回 true
  return true;
}

// GPS 初始化
void Initialize_GPS(unsigned long timeout_ms = 60000) {

  // 发送 GPS 开始初始化状态码
  Transmit_Status(GPS_INIT_START);
  unsigned long start = millis();

  // 调试模式下直接返回成功
  if (DEBUG_MODE) {
    Transmit_Status(GPS_INIT_OK);
    return;
  }

  // 在超时时间内不断尝试数据是否有效
  while (millis() - start < timeout_ms) {
    while (GPS_Serial.available()) {
      gps.encode(GPS_Serial.read());
    }

    if (gps.location.isValid()) {
      Transmit_Status(GPS_INIT_OK);

      // 构建一个初始遥测帧并发送
      Transmit_Text("%s", TelemetryMessage);

      return;
    }
    vTaskDelay(pdMS_TO_TICKS(2000));
  }

  Transmit_Status(GPS_INIT_FAIL, "Timeout");
  Initialization_Status = false;
}

// 初始化电压测量 ADC
void Initialize_Voltage_ADC() {
  // 配置 ADC 的通道衰减
  adc2_config_channel_atten(VOLTAGE_ADC_CHANNEL, VOLTAGE_ADC_ATTEN);
  // 获取 ADC 的校准特性
  esp_adc_cal_characterize(ADC_UNIT_2, VOLTAGE_ADC_ATTEN, VOLTAGE_ADC_WIDTH, VOLTAGE_ADC_VREF_MV, &adc_chars);
}

// 配置并初始化看门狗
void Initialize_Watchdog() {
  // 反初始化，确保后续状态干净
  esp_task_wdt_deinit();
  // 传入超时秒数和 panic 标志位
  esp_task_wdt_init(120, true);
}

// 定义数据链路层任务 (P5 - 最高优先级)
void V_Datalink_Task(void *pvParameters) {

  // 初始化帧缓冲区
  RadioPacket_t txPacket;
  static char frame_buffer[MAX_RX_BUFF_SIZE];
  static int frame_len = 0;

  // 将当前任务加入 WDT 监控 (注册看门狗)
  esp_task_wdt_add(NULL);

  for (;;) {

    // 标志位，记录本轮循环是否处理任何收发任务
    bool task_did_work = false;

    // 喂狗
    esp_task_wdt_reset();

    // 优先处理发送任务
    if (xQueueReceive(txQueue, &txPacket, pdMS_TO_TICKS(10)) == pdTRUE) {

      // 更新标志位
      task_did_work = true;

      // 从队列中获取数据包并写入串口
      Serial.write(txPacket.data, txPacket.length);
    }

    // 然后看看串口是否有数据，处理接收和分发
    if (Serial.available()) {

      // 更新标志位
      task_did_work = true;

      // 读取串口数据
      while (Serial.available()) {
        char c = Serial.read();

        // 检查帧尾 (换行符)
        if (c != '\n') {
          if (frame_len < MAX_RX_BUFF_SIZE - 1) {
            frame_buffer[frame_len++] = c;
          } else {
            // 缓冲区已满但未收到换行符，丢弃此帧，防止解析错误
            frame_len = 0;
          }
        }

        // 如果收到换行符，说明一帧数据接收完毕
        else {
          // 添加字符串结束符
          frame_buffer[frame_len] = '\0';

          // 判断帧类型并分发到对应的队列
          if (frame_len > 2) {

            // 指令帧 (@@)
            if (strncmp(frame_buffer, "@@", 2) == 0) {
              xQueueSend(cmdQueue, &frame_buffer[2], 50);
            }

            // 中继帧 (##)
            else if (strncmp(frame_buffer, "##", 2) == 0) {
              // 获取当前系统状态的副本
              SystemStatus_t local_status;
              GET_System_Status(&local_status);
              
              // 如果中继功能已启用且没有正在进行 SSDV 传输，则将数据包转发到中继队列
              if (local_status.isRelayEnabled && !local_status.isSsdvTransmitting) {
                xQueueSend(relayQueue, &frame_buffer[2], 50);
              }
            }
          }

          // 强制性让出 CPU 时间片，以进行指令解析
          vTaskDelay(pdMS_TO_TICKS(10));

          // 重置帧缓冲区，准备接收下一帧
          frame_len = 0;
        }
      }
    }

    // 如果既没有发送任务，也没有接收到数据，则短暂挂起，让出CPU
    if (!task_did_work) {
      vTaskDelay(pdMS_TO_TICKS(10));
    }
  }
}

// 创建数据链路任务
void Create_Datalink_Task() {

  // 初始化数据链路层各队列
  txQueue = xQueueCreate(60, sizeof(RadioPacket_t));
  cmdQueue = xQueueCreate(10, MAX_RX_BUFF_SIZE);
  relayQueue = xQueueCreate(10, MAX_RX_BUFF_SIZE);

  xTaskCreatePinnedToCore(
    V_Datalink_Task,           // 任务函数
    "DatalinkTask",            // 任务名称
    RTOS_STACK_SIZE,           // 堆栈大小
    NULL,                      // 传递参数
    configMAX_PRIORITIES - 1,  // 优先级P5
    &DatalinkTaskHandle,       // 任务句柄
    1                          // 运行核心
  );
}

// 处理 GET 指令的子函数
static void Handle_GET_Command(const char *target) {
  // 查询中继状态
  if (strcmp(target, "RELAY") == 0) {
    SystemStatus_t local_status;
    GET_System_Status(&local_status);
    Transmit_Status(CMD_ACK_GET_RELAY_STATUS, local_status.isRelayEnabled);
    return;
  }

  // 查询 SSDV 状态
  else if (strcmp(target, "SSDV") == 0) {
    SystemStatus_t local_status;
    GET_System_Status(&local_status);
    SystemConfig_t local_config;
    GET_System_Config(&local_config);
    Transmit_Status(CMD_ACK_GET_SSDV_STATUS, (int)local_status.isSsdvEnabled);
    Transmit_Status(CMD_ACK_GET_SSDV_CYCLE, (int)local_config.ssdvCycleTimeSec);
    Transmit_Status(CMD_ACK_GET_SSDV_TYPE, local_config.ssdvPacketType);
    Transmit_Status(CMD_ACK_GET_SSDV_QUALITY, (int)local_config.ssdvEncodingQuality);
    return;
  }

  // 查询摄像头参数
  else if (strcmp(target, "CAM") == 0) {
    SystemConfig_t local_config;
    GET_System_Config(&local_config);
    Transmit_Status(CMD_ACK_GET_CAM_SIZE, local_config.cameraImageSize);
    Transmit_Status(CMD_ACK_GET_CAM_QUALITY, local_config.cameraImageQuality);
    return;
  }

  else {
    Transmit_Status(CMD_NACK_INVALID_GET);
    return;
  }
}

// 处理 CTL 指令的子函数
static void Handle_CTL_Command(const char *target, const char *value) {

  // 系统控制命令
  if (strcmp(target, "SYS") == 0 && strcmp(value, "REBOOT") == 0) {
    Transmit_Status(SYS_RESTARTING);
    vTaskDelay(pdMS_TO_TICKS(1000));
    esp_restart();
    return;
  }

  // 中继状态控制命令
  else if (strcmp(target, "RELAY") == 0) {
    if (strcmp(value, "ON") == 0) {
      Update_System_Status(RELAY_ENABLED_STATUS, true);
      Transmit_Status(CMD_ACK_RELAY_ON);
    } else if (strcmp(value, "OFF") == 0) {
      Update_System_Status(RELAY_ENABLED_STATUS, false);
      Transmit_Status(CMD_ACK_RELAY_OFF);
    }
    return;
  }

  // SSDV 状态控制命令
  else if (strcmp(target, "SSDV") == 0) {
    if (strcmp(value, "ON") == 0) {
      Update_System_Status(SSDV_ENABLED_STATUS, true);
      Transmit_Status(CMD_ACK_SSDV_ON);
    } else if (strcmp(value, "OFF") == 0) {
      Update_System_Status(SSDV_ENABLED_STATUS, false);
      Transmit_Status(CMD_ACK_SSDV_OFF);
    }
    return;
  }

    // 如果所有命令都未匹配
  else {
    Transmit_Status(CMD_NACK_INVALID_CTL);
  }
}

// 处理 SET 指令的子函数
static void Handle_SET_Command(const char *target, const char *value) {

  // 获取状态体副本
  SystemStatus_t local_status;
  GET_System_Status(&local_status);

  // 前置检查：SSDV 正在传输时，不允许任何设置更改
  if (local_status.isSsdvTransmitting) {
    Transmit_Status(CMD_NACK_SSDV_BUSY);
    return;
  }

  // 处理所有摄像头相关设置命令 (CAM_SIZE、CAM_QUALITY) 
  if (strcmp(target, "CAM_SIZE") == 0 || strcmp(target, "CAM_QUALITY") == 0) {

    // 声明配置变更状态，获取当前配置的副本
    bool config_changed = false;
    SystemConfig_t temp_config;
    GET_System_Config(&temp_config);
    
    // 定义摄像头模式的静态常量数组
    static const struct {
      const char *name;
      int size;
    } cam_modes[] = {
      { "FHD" , FRAMESIZE_FHD  },
      { "SXGA", FRAMESIZE_SXGA },
      { "XGA" , FRAMESIZE_XGA  },
      { "VGA" , FRAMESIZE_VGA  },
      { "QVGA", FRAMESIZE_QVGA }
    };

    // 设置图像尺寸
    if (strcmp(target, "CAM_SIZE") == 0) {
      // 遍历 cam_modes 数组，找到与 value 相等的元素
      for (int i = 0; i < sizeof(cam_modes) / sizeof(cam_modes[0]); i++) {
        // 如果找到相等的元素，则将temp_config.cameraImageSize设置为该元素的size，并设置config_changed为true
        if (strcmp(value, cam_modes[i].name) == 0) {
          temp_config.cameraImageSize = (framesize_t)cam_modes[i].size;
          config_changed = true;
          // 发送 CMD_ACK_CAM_SIZE 响应，并附带 temp_config.cameraImageSize
          Transmit_Status(CMD_ACK_CAM_SIZE, temp_config.cameraImageSize);
          break;
        }
      }
      // 如果没有找到相等的元素，则发送 CMD_NACK_INVALID_TYPE 响应
      if (!config_changed) {
        Transmit_Status(CMD_NACK_INVALID_TYPE);
      }
    }

    // 设置图像质量
    else if (strcmp(target, "CAM_QUALITY") == 0) {
      int requested_quality = atoi(value);

      // 合法性检查
      if (requested_quality < 5 || requested_quality > 20) {
        Transmit_Status(CMD_NACK_SET_CAM_QUAL);
      } else if (temp_config.cameraImageSize > FRAMESIZE_SVGA && requested_quality < 10) {
        Transmit_Status(CMD_NACK_SET_CAM_QUAL_LOW);
      }
      
      // 通过后尝试进行设置
      else {
        temp_config.cameraImageQuality = requested_quality;
        config_changed = true;
        Transmit_Status(CMD_ACK_CAM_QUALITY, requested_quality);
      }
    }

    // 如果摄像头任一配置有变动，则统一执行重配
    if (config_changed) {

      // 获取摄像头硬件资源互斥锁进行保护
      xSemaphoreTake(cameraMutex, portMAX_DELAY);

      // 更新结构体内容并尝试进行设置
      Update_System_Config(&temp_config);
      if (Reconfigure_Camera()) {
        Transmit_Status(CAM_RECONFIG_OK);
      }

      // 如果设置失败，尝试恢复默认设置
      else {
        Transmit_Status(CAM_RECONFIG_FAIL);
        GET_System_Config(&temp_config);
        temp_config.cameraImageSize = FRAMESIZE_VGA;
        temp_config.cameraImageQuality = 5;
        Update_System_Config(&temp_config);
        if (Reconfigure_Camera()) {
          Transmit_Status(CAM_RESTORE_DEFAULT_OK);
        }
        
        // 恢复失败为重大失误，直接重启
        else {
          Transmit_Status(CAM_RESTORE_DEFAULT_FAIL);
          Transmit_Status(SYS_RESTARTING);
          esp_restart();
        }
      }

      // 释放锁
      xSemaphoreGive(cameraMutex);
    }

    // 处理完相机指令后直接返回
    return;
  }

  // 处理所有 SSDV 相关设置命令 (SSDV_TYPE, SSDV_QUALITY, SSDV_CYCLE)
  else if (strcmp(target, "SSDV_TYPE") == 0 || strcmp(target, "SSDV_QUALITY") == 0 || strcmp(target, "SSDV_CYCLE") == 0 || strcmp(target, "SSDV_PRESET") == 0) {
    
    // 声明配置变更状态，获取当前配置的副本
    bool config_changed = false;
    SystemConfig_t temp_config;
    GET_System_Config(&temp_config);

    // 设置 SSDV 类型
    if (strcmp(target, "SSDV_TYPE") == 0) {

      // 常规模式 (带有 FEC) 
      if (strcmp(value, "NORMAL") == 0) {
        temp_config.ssdvPacketType = SSDV_TYPE_NORMAL;
        config_changed = true;
        Transmit_Status(CMD_ACK_SSDV_TYPE, SSDV_TYPE_NORMAL);
      }
      
      // 轻量化模式 (无 FCE) 
      else if (strcmp(value, "NOFEC") == 0) {
        temp_config.ssdvPacketType = SSDV_TYPE_NOFEC;
        config_changed = true;
        Transmit_Status(CMD_ACK_SSDV_TYPE, SSDV_TYPE_NOFEC);
      }
      else {
        Transmit_Status(CMD_NACK_SET_SSDV_TYPE);
      }
    }

    // 设置 SSDV 质量
    else if (strcmp(target, "SSDV_QUALITY") == 0) {
      int quality = atoi(value);

      // 合法性校验
      if (quality >= 0 && quality <= 6) {
        temp_config.ssdvEncodingQuality = quality;
        config_changed = true;
        Transmit_Status(CMD_ACK_SSDV_QUALITY, quality);
      } else {
        Transmit_Status(CMD_NACK_SET_SSDV_QUAL);
      }
    }

    // 设置 SSDV 周期
    else if (strcmp(target, "SSDV_CYCLE") == 0) {
      int cycletime = atoi(value);

      // 合法性校验
      if (cycletime >= 10 && cycletime <= 100) {
        temp_config.ssdvCycleTimeSec = cycletime;
        config_changed = true;
        Transmit_Status(CMD_ACK_SSDV_CYCLE, cycletime);
      } else {
        Transmit_Status(CMD_NACK_SET_SSDV_CYCLE);
      }
    }

    else if (strcmp(target, "SSDV_PRESET") == 0) {
      int preset = atoi(value);

      // 合法性校验
      if (preset > 0 && preset <= 3) {
        temp_config.ssdvPresetMode = preset;
        config_changed = true;
        Transmit_Status(CMD_ACK_SSDV_PRESET, preset);
      } else {
        Transmit_Status(CMD_NACK_SET_SSDV_PRESET);
      }
    }

    // 如果 SSDV 配置发生变动，则统一更新到全局配置
    if (config_changed) {
      Update_System_Config(&temp_config);
    }

    // 处理完SSDV指令后直接返回
    return;
  }
  
  // 如果所有命令都未匹配
  else {
    Transmit_Status(CMD_NACK_INVALID_SET);
  }
}
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
void loop() {

  // 初始化结束后通过线程安全函数关闭蜂鸣器
  Update_System_Status(BUZZER_ENABLED_STATUS, false);

  // 删除主循环任务以释放资源
  vTaskDelete(NULL);
}

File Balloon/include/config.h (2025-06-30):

/*
 * Configuration and Global Declarations for the ESP32 HAB Tracker
 *
 * This header file centralizes all hardware pin assignments, firmware parameters,
 * global type definitions, and external variable declarations for the project.
 * It ensures a single, consistent source for configuration, which improves
 * modularity and simplifies maintenance across the firmware. All global objects
 * are declared here as 'extern' and defined in the main .ino file to adhere
 * to best practices and prevent linker errors.
 *
 * Author: BG7ZDQ
 * Date: 2025/06/21
 * Version: 1.0.1
 * LICENSE: GNU General Public License v3.0
 */

#ifndef CONFIG_H
#define CONFIG_H

/* --- 引入功能头文件 --- */

// Arduino 核心库
#include <Arduino.h>

// C/C++ 标准库 和 FreeRTOS
#include <stdarg.h>
#include <freertos/FreeRTOS.h>
#include <freertos/queue.h>
#include <freertos/task.h>

// ESP-IDF 底层驱动和库
#include <WiFi.h>
#include <SPIFFS.h>
#include <driver/adc.h>

#include <esp_camera.h>
#include <esp_adc_cal.h>
#include <esp_task_wdt.h>

#include <rom/rtc.h>
#include <rom/ets_sys.h>

#include <soc/sens_reg.h>
#include <soc/sens_reg.h>
#include <soc/rtc_cntl_reg.h>

// 第三方库
#include <TinyGPS++.h>
#include <ssdv.h>

/* --- 分配硬件引脚 --- */

// OV2640 摄像头模块引脚
#define CAM_PIN_Y9_GPIO_NUM      35
#define CAM_PIN_Y8_GPIO_NUM      34
#define CAM_PIN_Y7_GPIO_NUM      39
#define CAM_PIN_Y6_GPIO_NUM      36
#define CAM_PIN_Y5_GPIO_NUM      21
#define CAM_PIN_Y4_GPIO_NUM      19
#define CAM_PIN_Y3_GPIO_NUM      18
#define CAM_PIN_Y2_GPIO_NUM      5
#define CAM_PIN_XCLK_GPIO_NUM    0
#define CAM_PIN_PCLK_GPIO_NUM    22
#define CAM_PIN_VSYNC_GPIO_NUM   25
#define CAM_PIN_HREF_GPIO_NUM    23
#define CAM_PIN_SIOD_GPIO_NUM    26  // SCCB 接口
#define CAM_PIN_SIOC_GPIO_NUM    27  // SCCB 接口
#define CAM_PIN_PWDN_GPIO_NUM    32  // 电源控制
#define CAM_PIN_RESET_GPIO_NUM   -1  // 复位引脚 (未连接)

// 蜂鸣器引脚
#define BUZZER                   13

// 电压 ADC 引脚
#define VOLTAGE_ADC_GPIO_PIN     12  // 连接至分压电路的 ADC GPIO
#define VOLTAGE_ADC_CHANNEL      ADC2_CHANNEL_5


/* --- 固件参数与宏定义 --- */
#define CALLSIGN             "BG7ZDQ"            // 气球呼号

// RTOS 相关参数
#define RTOS_STACK_SIZE      4096                // 默认 RTOS 任务堆栈大小

// 缓冲区与数据包大小
#define MAX_TX_BUFF_SIZE     512                 // 发送队列缓冲区大小
#define MAX_RX_BUFF_SIZE     512                 // 接收队列缓冲区大小
#define SSDV_FEED_BUFF_SIZE  128                 // 喂给 SSDV 编码器的缓冲区大小
#define SSDV_OUT_BUFF_SIZE   256                 // 存放 SSDV 数据包的缓冲区大小
#define SSDV_SIZE_NOFEC      256                 // 单个 SSDV 数据包的大小

// 功能参数
#define CAM_CALIBRATE_TIMES  8                   // 摄像头校准拍摄次数

// 电压测量相关参数
#define VOLTAGE_TEST_R1      10000               // 分压电阻 R1 的阻值
#define VOLTAGE_TEST_R2      1000                // 分压电阻 R2 的阻值
#define VOLTAGE_ADC_WIDTH    ADC_WIDTH_BIT_12    // 电压测量 ADC 的分辨率
#define VOLTAGE_ADC_ATTEN    ADC_ATTEN_DB_0      // 电压测量 ADC 的输入衰减
#define VOLTAGE_ADC_VREF_MV  1100                // 电压测量 ADC 的参考电压 (mV)


/* --- 全局数据结构类型定义 --- */

// 声明系统动态配置参数结构体
typedef struct {
  framesize_t cameraImageSize;      // 摄像头图像尺寸
  int         cameraImageQuality;   // 摄像头图像质量
  uint8_t     ssdvPacketType;       // SSDV 数据类型
  int         ssdvEncodingQuality;  // SSDV 编码质量
  int         ssdvCycleTimeSec;     // SSDV 发送周期
  int         ssdvPresetMode;       // SSDV 预设图片功能
} SystemConfig_t;

// 声明系统实时运行状态结构体
typedef struct {
  bool isRelayEnabled;              // 中继功能启用状态
  bool isSsdvEnabled;               // 图传功能启用状态
  bool isBuzzerEnabled;             // 蜂鸣功能启用状态
  bool isSsdvTransmitting;          // 图像传输进行状态
} SystemStatus_t;

// 声明用于安全更新系统状态的枚举
typedef enum {
  RELAY_ENABLED_STATUS,
  SSDV_ENABLED_STATUS,
  BUZZER_ENABLED_STATUS,
  SSDV_TRANSMITTING_STATUS,
} SystemStatusParam_t;

// 声明无线电发送队列的数据包结构体
typedef struct {
  uint8_t data[MAX_TX_BUFF_SIZE];
  size_t length;
  bool is_binary;
} RadioPacket_t;


/* --- 全局变量外部声明 --- */

// 系统配置与状态变量
extern SystemConfig_t g_systemConfig;
extern SystemStatus_t g_systemStatus;
extern bool Initialization_Status;

// 声明互斥锁
extern SemaphoreHandle_t g_configMutex;  // 配置参数结构体互斥锁
extern SemaphoreHandle_t g_stateMutex;   // 状态参数结构体互斥锁
extern SemaphoreHandle_t cameraMutex;    // 摄像头硬件资源互斥锁

// 声明各类队列
extern QueueHandle_t txQueue;            // 数据发送队列
extern QueueHandle_t cmdQueue;           // 命令接收队列
extern QueueHandle_t relayQueue;         // 中继信息队列

// FreeRTOS 任务句柄
extern TaskHandle_t DatalinkTaskHandle;
extern TaskHandle_t CommandTaskHandle;
extern TaskHandle_t TelemetryTaskHandle;
extern TaskHandle_t SSDVTaskHandle;
extern TaskHandle_t RelayTaskHandle;

// 遥测模块相关变量
extern char TelemetryMessage[256];
extern uint16_t Telemetry_Counter;

// GPS 模块相关对象
extern HardwareSerial GPS_Serial;
extern char GPS_Timestamp[21];
extern TinyGPSPlus gps;

// ADC 及传感器相关变量
extern esp_adc_cal_characteristics_t adc_chars;

// SSDV 模块相关变量
extern ssdv_t ssdv;
extern uint8_t ssdvImageId;

#endif // CONFIG_H

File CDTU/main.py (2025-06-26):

"""
Program for HAB Transceiver.

This program is used to turn a MicroPython board into a smart
Configurable Data Transfer Unit for HC-12 transceiver module. 

It provides Transparent Data Bridge, Runtime AT Command Control,
Persistent Configuration and Automatic Mode Switching.

Author: BG7ZDQ
Date: 2025/06/27 
Version: 0.0.2 
LICENSE: GNU General Public License v3.0
"""

import sys
import time
import select
import neopixel
from machine import UART, Pin

""" 参数定义 """
# 允许的波特率与信道号
# 此处挑选效率最高的选项，同时确保处于业余无线电频段
VALID_BAUD = {2400, 9600, 38400, 115200}
VALID_CHAN = {f"{i:03d}" for i in range(1, 17)}

# AT 参数定义
AT_MODE_ENTRY_DELAY_S = 0.05  # 进入AT模式需要的稳定时间
AT_MODE_EXIT_DELAY_S = 0.1    # 退出AT模式后模块重启时间
AT_CMD_INTERVAL_S = 0.1       # 发送AT指令后所需等待时间

# 硬件引脚定义
CTRL_PIN = Pin(6, Pin.OUT)
UART_TX_PIN = Pin(4)
UART_RX_PIN = Pin(5)
UART_ID = 1

# LED 颜色定义 (R, G, B)
COLOR_STANDBY = (16, 0, 0)  # 待机 - 红色
COLOR_USB_RX = (0, 16, 0)   # 收到上位机(USB)数据 - 绿色
COLOR_UART_RX = (0, 0, 16)  # 收到串口(无线模块)数据 - 蓝色

# 配置文件名
CONFIG_FILE = "config.ini"

# 上电时进入AT指令模式的固定通信参数
POWER_ON_AT_MODE_BAUD_RATE = 9600

# 当前模块的运行波特率
current_baud_rate = 0 

# 运行状态
state = True


""" LED 状态控制器定义 """
class StatusLED:
    def __init__(self, pin, flash_duration_ms=10):
        self.np = neopixel.NeoPixel(Pin(pin), 1)
        self.flash_duration_ms = flash_duration_ms
        
        # 记录上次颜色改变的时间戳
        self.last_change_time = 0
        self.is_flashing = False

        # 设置初始待机颜色
        self.set_color(COLOR_STANDBY)

    def set_color(self, color):
        """直接设置LED颜色"""
        self.np[0] = color
        self.np.write()

    def trigger_flash(self, flash_color):
        """触发一次指定颜色的闪烁"""
        self.set_color(flash_color)
        self.last_change_time = time.ticks_ms()
        self.is_flashing = True

    def update(self):
        """在主循环中不断调用此方法来更新LED状态"""
        # 仅当LED处于闪烁状态时才需要检查
        if self.is_flashing:
            # 如果距离上次闪烁已经超过了设定的时间
            if time.ticks_diff(time.ticks_ms(), self.last_change_time) > self.flash_duration_ms:
                self.set_color(COLOR_STANDBY)
                self.is_flashing = False
                
""" 函数定义 """
# 验证波特率是否有效
def is_valid_baud(baud):
    return baud in VALID_BAUD

# 验证信道号是否有效
def is_valid_chan(chan):
    return chan in VALID_CHAN

# 从 config.ini 读取配置
def read_config():
    default_baud = 9600
    default_chan = "006"

    try:
        # 打开配置文件
        with open(CONFIG_FILE, "r") as f:
            config_data = {}
            # 设置配置格式
            for line in f:
                if '=' in line:
                    key, value = line.strip().split('=', 1)
                    config_data[key] = value

            # 读取字段值
            baud_str = config_data.get("baud")
            chan_str = config_data.get("chan")
            baud = int(baud_str) if baud_str else None
            chan = str(chan_str) if chan_str else None
            
            # 验证读取到的值
            if baud and is_valid_baud(baud) and chan and is_valid_chan(chan):
                return baud, chan
            else:
                raise ValueError("Invalid config parameters")

    # 处理文件不存在或内容无效的情况
    except (OSError, ValueError) as e:
        if isinstance(e, OSError):
            usb_log("** [注意] 配置文件未找到，将使用默认配置 **\n")
        else:
            usb_log("** [错误] 配置文件值无效，将使用默认配置 **\n")
        
        update_config(default_baud, default_chan)
        return default_baud, default_chan
    # 处理其他异常错误
    except Exception as e:
        usb_log(f"** [错误] 配置文件读取异常，将使用默认配置: {e} **\n")
        return default_baud, default_chan

# 更新 config.ini 文件
def update_config(baud=None, chan=None):
    config = {}
    changed = False

    # 读取先前的配置
    try:
        with open(CONFIG_FILE, "r") as f:
            for line in f:
                if '=' in line:
                    k, v = line.strip().split('=', 1)
                    config[k] = v

    # 配置文件不存在
    except OSError:
        config = {}
        changed = True

    # 判断是否需要更新波特率
    if baud is not None and is_valid_baud(baud):
        if config.get("baud") != str(baud):
            config["baud"] = str(baud)
            changed = True

    # 判断是否需要更新信道号
    if chan is not None and is_valid_chan(chan):
        if config.get("chan") != chan:
            config["chan"] = chan
            changed = True
    
    # 若配置未变，则无需写入文件
    if not changed:
        return

    # 尝试写回配置文件
    try:
        with open(CONFIG_FILE, "w") as f:
            for k, v in config.items():
                f.write(f"{k}={v}\n")
    except OSError as e:
        usb_log(f"** [错误] 配置文件更新失败: {e} **\n")


# 初始化/重新初始化 UART
def init_uart(baud):
    try:
        return UART(UART_ID, baudrate=baud, tx=UART_TX_PIN, rx=UART_RX_PIN, rxbuf=256)
    except Exception as e:
        usb_log(f"** [错误] 初始化 UART 时出错: {e} **\n")
        return None

# 向USB串口写入原始二进制数据
def usb_raw(data):
    if isinstance(data, bytearray):
        data = bytes(data)
    elif not isinstance(data, bytes):
        raise TypeError("** [错误] RAW 函数需要字节或字节数组 **\n")
    sys.stdout.buffer.write(data)

# 向USB串口写入 UTF-8 编码的调试或提示信息
def usb_log(message):
    if not isinstance(message, bytes):
        message = str(message).encode("utf-8")
    sys.stdout.buffer.write(message)

# 进入AT指令模式
def enter_at_mode():
    CTRL_PIN.value(0)
    time.sleep(AT_MODE_ENTRY_DELAY_S)

# 退出AT指令模式
def exit_at_mode():
    CTRL_PIN.value(1)
    time.sleep(AT_MODE_EXIT_DELAY_S)
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

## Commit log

2025-05-28 将请求封装为了函数，另外新增了地面站位置回报。
2025-05-29 添加数据通信窗口，完善各类细节，修复一些BUG，规整代码结构。台站信息现在改为由配置文件存储。
2025-05-29 将存在问题的NeoGPS库切换为TinyGPS，添加数据中继功能，遥测RTOS任务化。
2025-06-01 试验并完善了日志记录逻辑与条件。修复了重复记录多次的Bug
2025-06-02 SSDV任务化，增加互斥锁、看门狗等机制。【重要】：因为硬件故障此代码并未进行实际验证
2025-06-06 中继部分新增UTF-8支持，更改首次运行逻辑，优化用户体验
2025-06-06 修复了RTOS的若干调度与看门狗问题，优化了能源调度
2025-06-06 最新版本。注意：该版本尚未经过验证
2025-06-07 新增了温度传输，修改了一些提示信息，暂时遏制了多核的串口冲突
2025-06-07 新增温度参数的传输，修复了一些小问题
2025-06-07 新增电压测量电路，预留HC-12的SET连接
2025-06-13 feat: 新增CDUT数据中间件及相关硬件设计，完善上位机对接逻辑
    - 新增 CDUT 数据中间件的代码实现
    - 完成中间件配套电路及外壳结构设计
    - 上位机完善旋转器控制逻辑及与 CDUT 的通信接口
    - 更新气球硬件版本，适配中间件新增功能
    [CDTU_盒子.stl, CDUT_盖子.stl]
2025-06-13 docs: 更新 README.md，添加配图，详细介绍各部分功能
2025-06-14 [docs] 优化排版结构，缩减图像大小，丰富信息
2025-06-15 [Docs] 修复配图错误问题
2025-06-15 [Docs] 优化文本排版
2025-06-15 chore: 复制代码文件并更改后缀，便于 AI 阅读处理
2025-06-15 [feat] 新增波特率自动探测并重构指令处理
    本次提交引入了AT通信波特率自动探测功能，并对指令处理核心逻辑进行了彻底重构，以提高程序的健壮性和可维护性。
    主要更新包括：
    - **自动探测**: 新增 `find_at_baud_rate` 函数，在设备初始化时自动尝试多个波特率以建立稳定的AT连接，极大地提高了在未知或配置变更后的启动可靠性。
    - **结构化解析**: 用 `parse_usb_command` 和 `execute_at_command` 替代了原有的指令处理函数。新的解析器返回结构化的指令类型（配置、查询、控制、错误），使指令执行逻辑更清晰、健壮，易于扩展。
    - **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
2025-06-15 [Refactor] 简化调试逻辑并移除串口互斥锁 (core)
    - 移除了 `DEV_Pass()` 函数，统一使用 `DEBUG_MODE` 宏进行条件判断，使调试流程更直接、更易于理解。
    - 删除了 `Transmit_Text` 和 `Transmit_Data` 函数中的串口互斥锁（`xSerialMutex`），以避免无端故障。
    - 重构了 `V_Transmit_GPS_Task` 任务，消除了在调试模式和正常模式下的重复代码块，提高了代码的可读性和可维护性。
2025-06-24 [feat] 全面重构固件、地面站与CDTU，迁移工具链并新增功能
    feat(firmware): 重构为五层架构，新增电池电压检测与命令注释功能
    - 采用五层架构重新组织固件结构
    - 新增电池电压检测模块
    - 引入命令上注功能以提升可扩展性
    - 工具链迁移至 PlatformIO，便于后续维护与构建管理
    feat(gs): 重构地面站，新增命令发送窗口并适配新遥测帧格式
    - 重构整体结构，提升代码可读性
    - 新增命令发送窗口功能
    - 适配新遥测帧格式
    - 去定制化处理，使其更易用于他人项目
    refactor(cdtu): 修正拼写错误，更新封装并重制外壳
    - 修正原设计中拼写错误
    -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
    [CDTU_盒子.stl, CDUT_盖子.stl]
2025-06-24 [Doc] 初步更新了各部分的说明，上传了独立的图片文件夹以方便更改。
2025-06-26 [refactor] 重构LED控制并增强程序健壮性
    本次提交对代码进行了重要的重构和加固，旨在提高程序的稳定性和可维护性。
    主要变更包括：
    - 引入 StatusLED 类: 将LED状态（常亮、闪烁）的控制逻辑封装起来，使主循环和业务逻辑分离，代码结构更清晰。
    - 增强错误处理:
    - 为 `init_uart` 函数增加了 `try...except` 语句，防止串口初始化失败时程序崩溃。
    - 重写了 `find_at_baud_rate` 的逻辑，确保在尝试通信失败后能正确关闭串口资源，避免泄露。
    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
2025-06-26 fix(firmware): 修复SSDV图像传输末尾数据损坏问题
    在高负载的图像传输任务结束时，最后一个或倒数第二个SSDV数据包经常出现损坏或丢失。
    这是由一个竞态条件 (Race Condition) 引起的：
    V_SSDV_Task在发送队列 (txQueue) 清空后，错误地认为物理传输已完成，并立即将CPU频率从240MHz降至80MHz以节省电能。
    然而，此时高优先级的V_Datalink_Task可能仍在通过物理串口发送最后一个数据包的字节。CPU频率的突变导致UART波特率时钟错乱，从而破坏了正在传输的数据。
    此修复通过在V_SSDV_Task检测到队列为空后，和降低CPU频率之前，增加一个500毫秒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
    [main.cpp]
2025-06-26 chore: 调整文本格式，增加缺失的换行符
2025-06-26 chore: 修正错误的版本号
2025-06-26 docs(log): 优化日志风格，调整日志目录
2025-06-26 chore(web): 调整web部分的目录，使其从地面站组件独立出来
2025-06-27 fix: 移除不受支持的SVGA图像，修复地面站部分逻辑错误
2025-06-27 fix: 多项问题修复与功能增强
    ### 修复内容
    - 修复中继窗口返回键显示异常
    - 修复依赖文件检测机制，改为使用绝对路径判断
    - 修复信息发送失败计数器未正确增加的问题
    - 修复图像传输参数错误时未发送 NACK 的问题
    - 修复 SVGA 编码异常，替换为 XGA 格式
    ### 新增功能
    - 支持通过 `@@SET,SSDV_PRESET` 命令设置预设图片
    - 重写platformio.ini文件，搭配自动化脚本spiffs_uploader.py，实现一键上传
    [GUI.py, config.h, main.cpp]
2025-06-30 feat(command): 添加上行链路密码验证机制，防止未授权控制
2025-06-30 fix(command): 修复密码校验时字段不完整造成的崩溃。同时对MAX-M10S GNSS模块做适配
2025-06-30 fix(SSDV): SSDV图像编码过程可能发生死锁，拟进行函数内检查。
2025-07-01 fix: 针对实际应用环境，做出细节修改，使其更易用。
2025-07-06 Update web assets and add installer script
    Added new firmware and documentation files, a web asset archive, and an Inno Setup installer script for the ground station. Updated Web/index.html to change iframe sources and parameters, and adjuste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
2025-07-06 完结撒花！更新飞行数据！
